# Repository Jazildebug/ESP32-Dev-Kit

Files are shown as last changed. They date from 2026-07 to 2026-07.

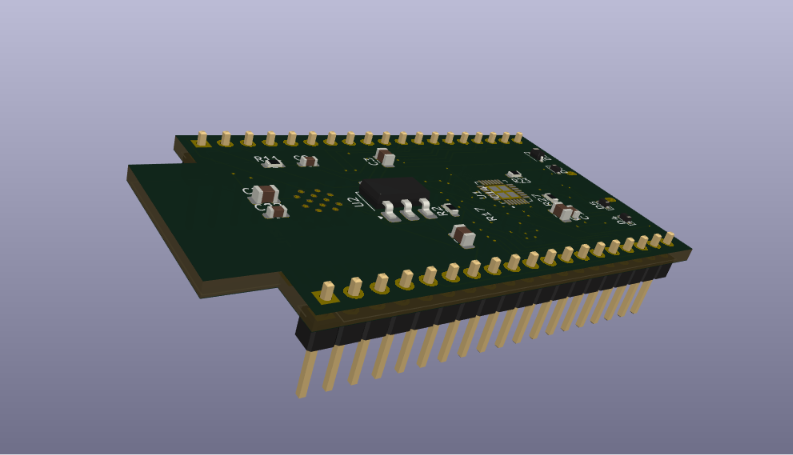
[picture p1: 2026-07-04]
PROJECT IMAGES/Screenshot 2026-07-04 184100.png

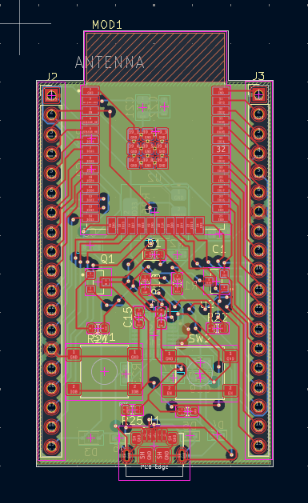
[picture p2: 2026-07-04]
PROJECT IMAGES/Screenshot 2026-07-04 183806.png

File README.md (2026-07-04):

# ESP32-Dev-Kit
KiCad project files for an ESP32 development board — schematic, PCB layout, and footprints for a custom dev kit design.
ESP32 Dev Kit — KiCad Design Files
This repository contains the complete KiCad project for a custom ESP32 development board, including schematic capture, PCB layout, and associated footprints/symbols.
Contents:

Schematic (.kicad_sch) — ESP32 module wiring, power regulation, USB-to-serial interface, and GPIO breakout
PCB layout (.kicad_pcb) — routed board with defined net classes and design rules
Footprint and symbol libraries used in the design
Gerber/production files (if included — add or remove this line)

Features:

ESP32-WROOM/WROVER module support
USB-to-UART programming circuit
Onboard 3.3V voltage regulation
Breakout headers for GPIO access
Reset/boot button configuration

Tools used: KiCad 10.0
Feel free to open, modify, or fork this design for your own ESP32-based projects.

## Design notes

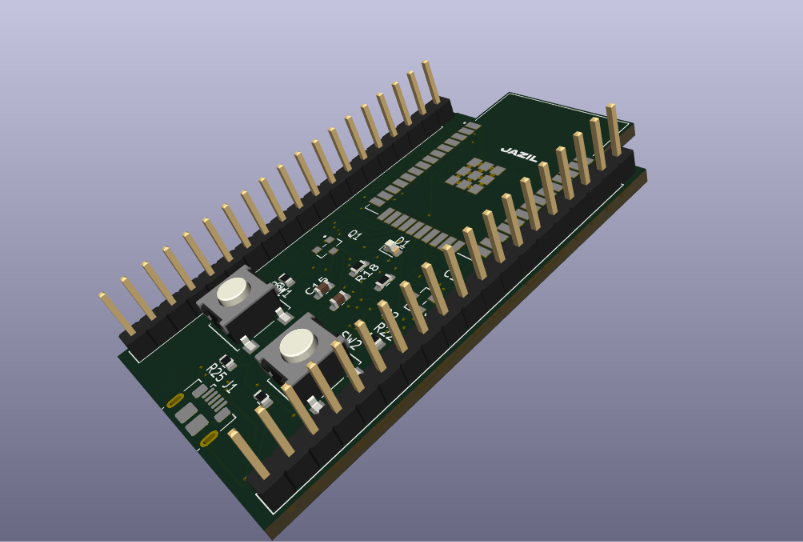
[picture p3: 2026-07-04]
PROJECT IMAGES/Screenshot 2026-07-04 184047.png

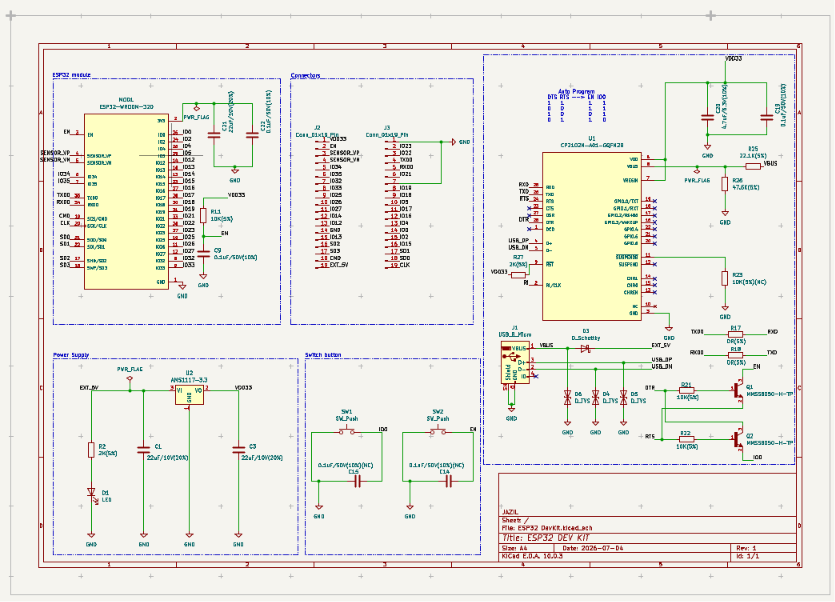
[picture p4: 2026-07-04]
PROJECT IMAGES/Screenshot 2026-07-04 183705.png

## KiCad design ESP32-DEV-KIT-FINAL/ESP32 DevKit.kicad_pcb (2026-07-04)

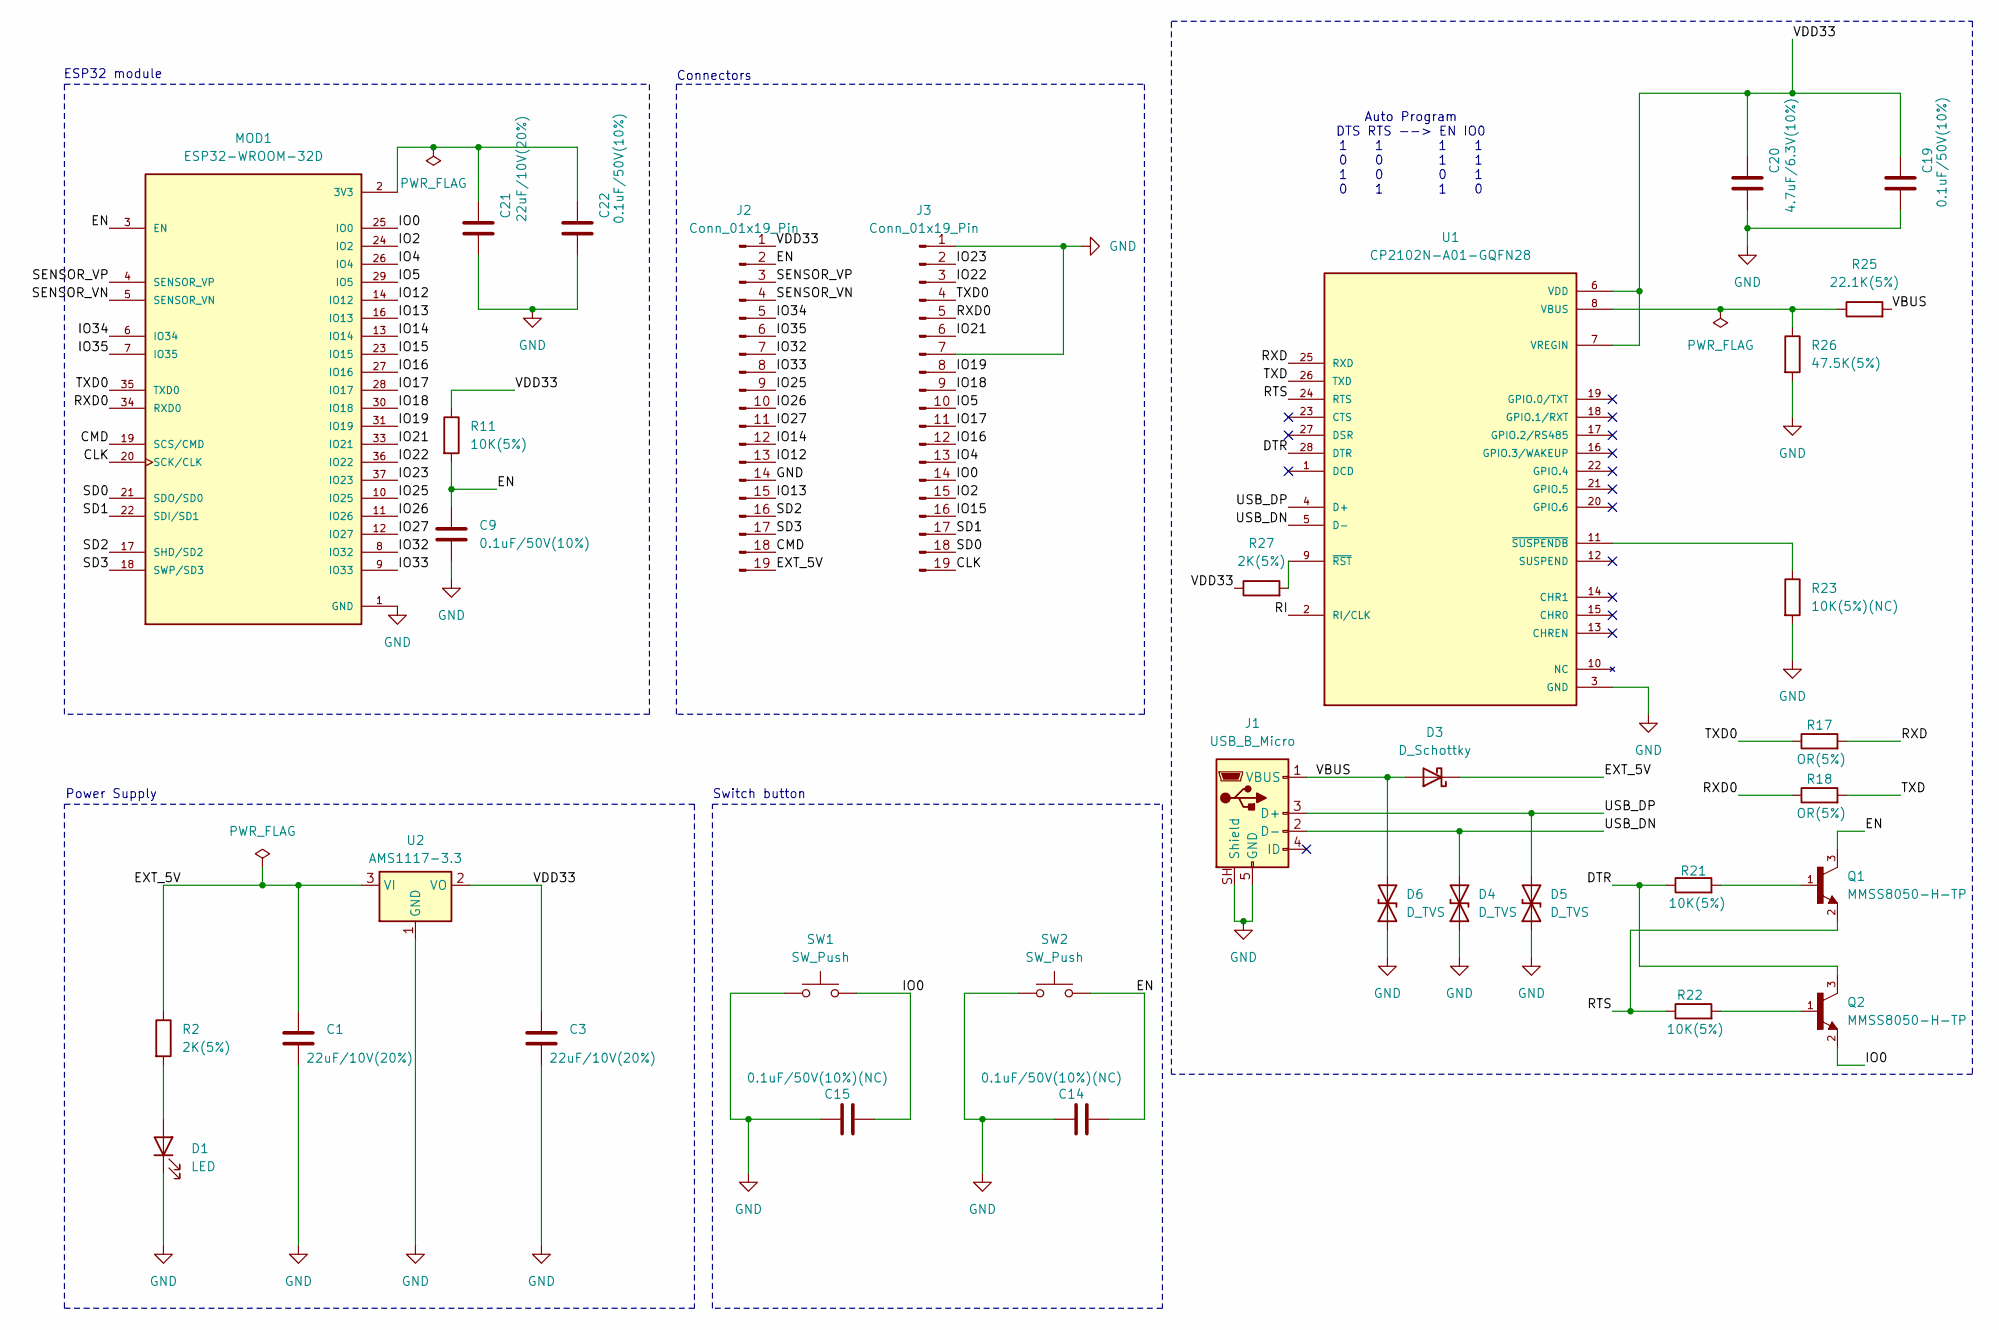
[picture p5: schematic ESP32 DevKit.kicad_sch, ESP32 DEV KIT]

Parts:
C1, C3, C21: 22uF/10V(20%); C_0805_2012Metric
C9, C19, C22: 0.1uF/50V(10%); C_0603_1608Metric
C14, C15: 0.1uF/50V(10%)(NC); C_0603_1608Metric
C20: 4.7uF/6.3V(10%); C_0805_2012Metric
D1: LED; LED_0603_1608Metric
D3: D_Schottky; D_SOD-323
D4, D5, D6: D_TVS; D_SOD-523
J1: USB_B_Micro; USB_Micro-B_GCT_USB3076-30-A
J2, J3: Conn_01x19_Pin; PinHeader_1x19_P2.54mm_Vertical
MOD1: ESP32-WROOM-32D; MODULE_ESP32-WROOM-32D; PARTREV 1.9
Q1, Q2: MMSS8050-H-TP; PARTREV D
R2, R27: 2K(5%); R_0603_1608Metric
R11, R21, R22: 10K(5%); R_0603_1608Metric
R17, R18: OR(5%); R_0603_1608Metric
R23: 10K(5%)(NC); R_0603_1608Metric
R25: 22.1K(5%); R_0603_1608Metric
R26: 47.5K(5%); R_0603_1608Metric
SW1, SW2: SW_Push; SW_SPST_B3S-1000
U1: CP2102N-A01-GQFN28; CP2102N; PARTREV 1.0
U2: AMS1117-3.3; SOT-223-3_TabPin2

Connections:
/CLK: J3.19, MOD1.20 (SCK/CLK)
/CMD: J2.18, MOD1.19 (SCS/CMD)
/DTR: Q2.3, R21.1, U1.28 (DTR)
/EN: C9.1, C14.2, J2.2, MOD1.3 (EN), Q1.3, R11.2, SW2.2
/EXT_5V: C1.1, D3.1 (K), J2.19, R2.1, U2.3 (VI)
/IO0: C15.2, J3.14, MOD1.25 (IO0), Q2.2, SW1.2
/IO2: J3.15, MOD1.24 (IO2)
/IO4: J3.13, MOD1.26 (IO4)
/IO5: J3.10, MOD1.29 (IO5)
/IO12: J2.13, MOD1.14 (IO12)
/IO13: J2.15, MOD1.16 (IO13)
/IO14: J2.12, MOD1.13 (IO14)
/IO15: J3.16, MOD1.23 (IO15)
/IO16: J3.12, MOD1.27 (IO16)
/IO17: J3.11, MOD1.28 (IO17)
/IO18: J3.9, MOD1.30 (IO18)
/IO19: J3.8, MOD1.31 (IO19)
/IO21: J3.6, MOD1.33 (IO21)
/IO22: J3.3, MOD1.36 (IO22)
/IO23: J3.2, MOD1.37 (IO23)
/IO25: J2.9, MOD1.10 (IO25)
/IO26: J2.10, MOD1.11 (IO26)
/IO27: J2.11, MOD1.12 (IO27)
/IO32: J2.7, MOD1.8 (IO32)
/IO33: J2.8, MOD1.9 (IO33)
/IO34: J2.5, MOD1.6 (IO34)
/IO35: J2.6, MOD1.7 (IO35)
/RI: U1.2 (RI/CLK)
/RTS: Q1.2, R22.1, U1.24 (RTS)
/RXD: R17.2, U1.25 (RXD)
/RXD0: J3.5, MOD1.34 (RXD0), R18.1
/SD0: J3.18, MOD1.21 (SDO/SD0)
/SD1: J3.17, MOD1.22 (SDI/SD1)
/SD2: J2.16, MOD1.17 (SHD/SD2)
/SD3: J2.17, MOD1.18 (SWP/SD3)
/SENSOR_VN: J2.4, MOD1.5 (SENSOR_VN)
/SENSOR_VP: J2.3, MOD1.4 (SENSOR_VP)
/TXD: R18.2, U1.26 (TXD)
/TXD0: J3.4, MOD1.35 (TXD0), R17.1
/USB_DN: D4.2 (A2), J1.2 (D-), U1.5 (D-)
/USB_DP: D5.2 (A2), J1.3 (D+), U1.4 (D+)
/VBUS: D3.2 (A), D6.2 (A2), J1.1 (VBUS), R25.2
/VDD33: C3.1, C19.1, C20.1, J2.1, R11.1, R27.1, U1.6 (VDD), U1.7 (VREGIN), U2.2 (VO)
GND: C1.2, C3.2, C9.2, C14.1, C15.1, C19.2, C20.2, C21.2, C22.2, D1.1 (K), D4.1 (A1), D5.1 (A1), D6.1 (A1), J1.5 (GND), J1.SH (Shield), J2.14, J3.1, J3.7, MOD1.1 (GND), MOD1.15 (GND), MOD1.38 (GND), MOD1.39_1 (GND), MOD1.39_2 (GND), MOD1.39_3 (GND), MOD1.39_4 (GND), MOD1.39_5 (GND), MOD1.39_6 (GND), MOD1.39_7 (GND), MOD1.39_8 (GND), MOD1.39_9 (GND), MOD1.39_10 (GND), MOD1.39_11 (GND), MOD1.39_12 (GND), MOD1.39_13 (GND), MOD1.39_14 (GND), MOD1.39_15 (GND), MOD1.39_16 (GND), MOD1.39_17 (GND), MOD1.39_18 (GND), MOD1.39_19 (GND), MOD1.39_20 (GND), MOD1.39_21 (GND), R23.2, R26.2, SW1.1, SW2.1, U1.3 (GND), U1.29 (GND), U2.1 (GND)
unnamed: D1.2 (A), R2.2
unnamed: C21.1, C22.1, MOD1.2 (3V3)
unnamed: Q1.1, R21.2
unnamed: Q2.1, R22.2
unnamed: R25.1, R26.1, U1.8 (VBUS)
unnamed: R27.2, U1.9 (~RST)
unnamed: R23.1, U1.11 (~SUSPENDB)

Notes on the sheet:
Auto Program DTS RTS --> EN IO0 1 1 1 1 0 0 1 1 1 0 0 1 0 1 1 0
Switch button
Power Supply
Connectors
ESP32 module

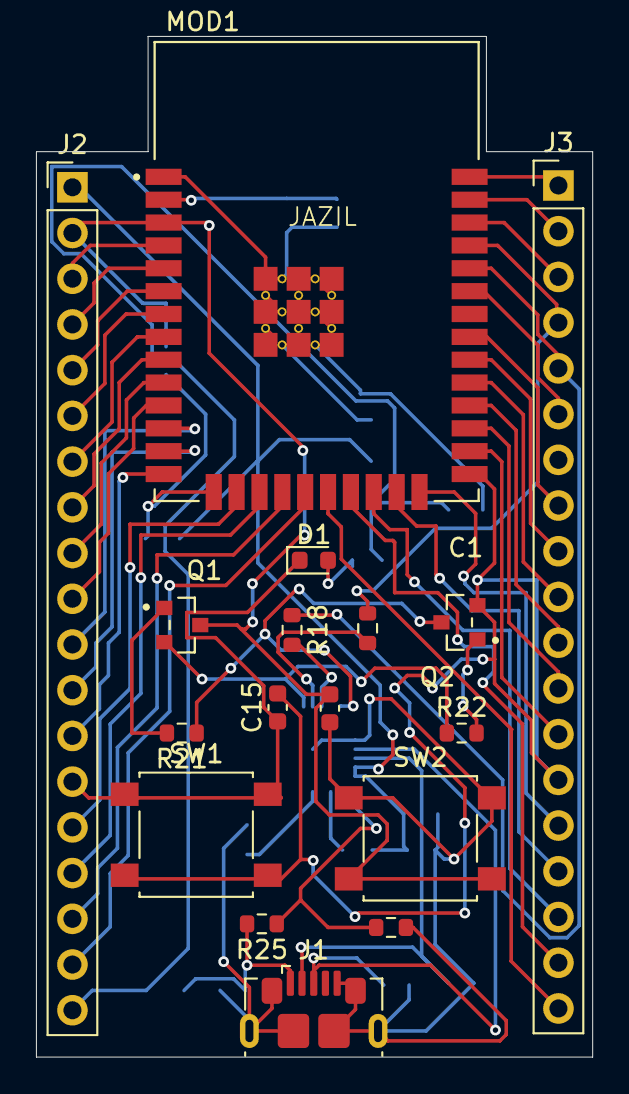
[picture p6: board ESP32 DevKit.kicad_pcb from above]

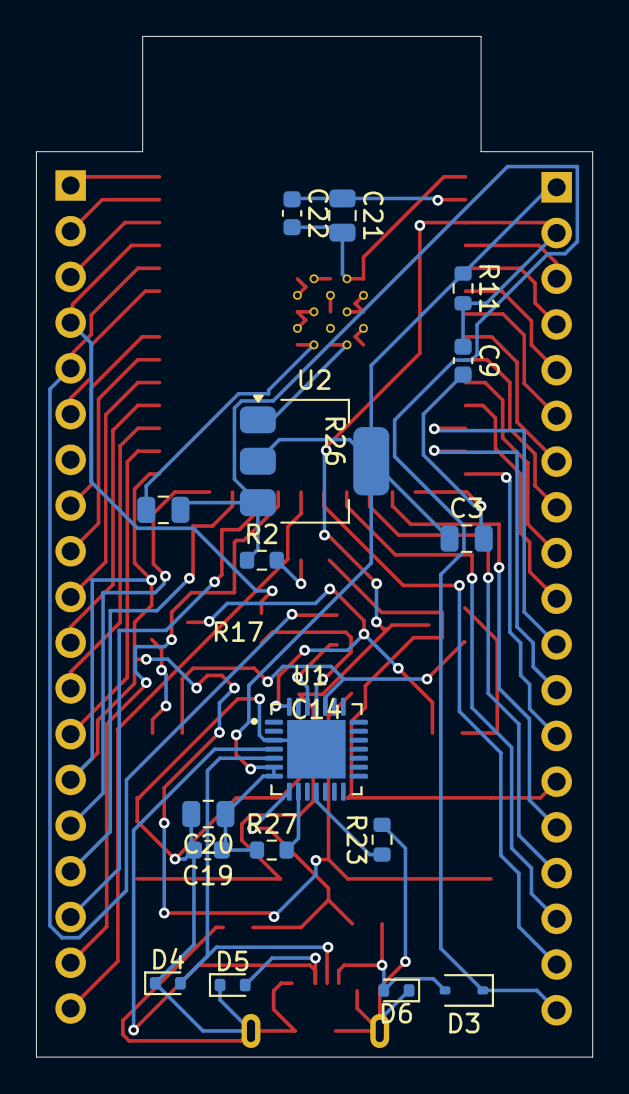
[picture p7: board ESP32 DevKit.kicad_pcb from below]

Board: 4 copper layers, 30.9 x 56.7 mm, 34 parts (17 on the bottom side), 50 nets.

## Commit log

2026-07-04 uploading images
    [ESP32 DevKit-B_Cu.gbr, ESP32 DevKit-B_Mask.gbr, ESP32 DevKit-B_Paste.gbr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]
2026-07-04 uploading esp32 dev kit and images
    [ESP32 DevKit.kicad_pcb, ESP32 DevKit.kicad_sch, USB-UART.kicad_sch]
